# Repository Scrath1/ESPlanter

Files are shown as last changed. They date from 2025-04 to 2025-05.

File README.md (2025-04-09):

# ESPlanter - An ESP32-based smart planter system for use with Homeassistant



A smart planter based on an ESP32 which integrates to homeassistant using
the MQTT integration and by sending an auto-discovery message.

The planter itself does not decide on when water is needed. It only exposes its
sensors and a button (to trigger the pump) for the homeassistant server to control.

## Required Parts:
- 1x Seeed XIAO ESP32C3
  (If you want to use a different device, modify the platformio.ini file)
- 5V Mini 360 Self-priming water pump
- 1x NPN Transistor which can handle the pump current.
  I used a BC107A because I had a couple already.
- 1x BH1750 light sensor
- 1x Capacitive Soil moisture sensor
- 1x 220 Ohm resistor
- 1x Diode
- Connectors if you want to use them
- Flexible tube for the water pump. Mine has an inner diameter of 4mm but make sure
  to check your pump if you require a different diameter.

## Circuit diagram
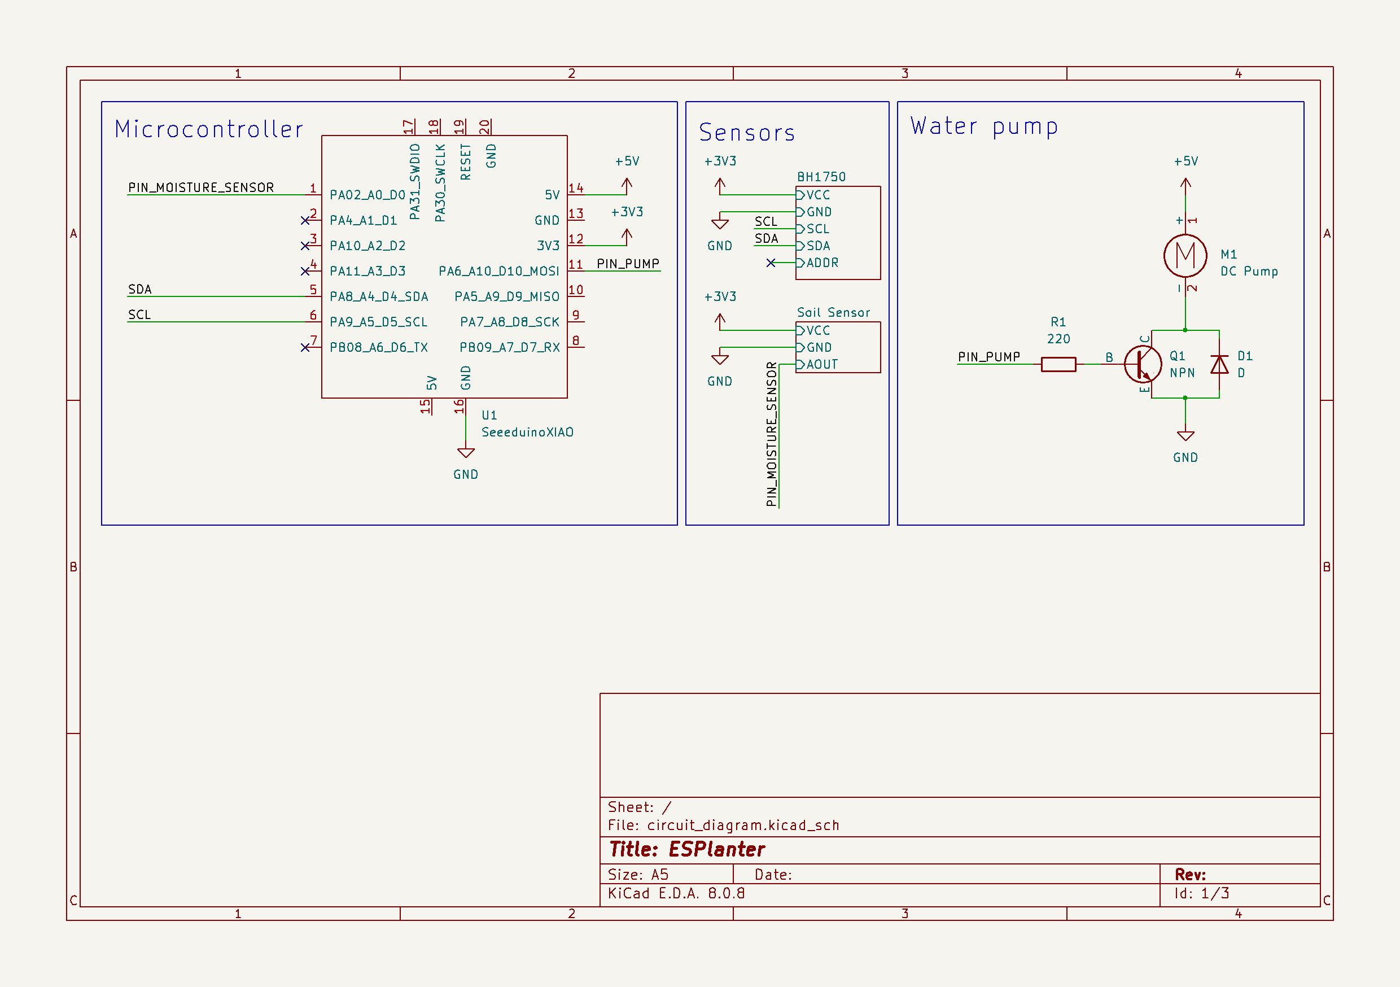
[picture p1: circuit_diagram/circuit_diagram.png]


## Setup
After flashing the device open the serial monitor to configure it.
Type `help` and confirm by pressing enter, to list all available commands.
Type `list` to print all currently supported configuration values and their current
values.

By typing `set <config value name>:<value>` you can change the value of these entries
for your particular setup. Important values to configure are the WiFi SSID and
password, the MQTT broker address as well as the username and password if your server
requires authentication.

## Calibrating the soil sensor
In order for the soil sensor to measure sensible values it needs to be calibrated.
To do this, use the serial interface and type the command `read_moisture_sensor`.
This will print the currently measured moisture as a percentage as well as the
raw value read by the ADC.

1. While the sensor is perfectly dry, obtain a raw sensor reading and set this
   as the upper limit (using the method described in [Setup](#setup)).
2. Take a cup of water and insert the sensor up to the printed line on the circuit
   board. Take another raw sensor reading and set this value as the lower limit.
3. Take a new sensor reading while the sensor is still in the water cup.
   The percentage should now show approximately 100% moisture.

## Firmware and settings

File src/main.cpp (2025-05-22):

#include <Arduino.h>
#include <LittleFS.h>

#include "drivers/light_sensor.h"
#include "drivers/pump.h"
#include "drivers/soil_sensor.h"
#include "global.h"
#include "mqtt_functions.h"
#include "serial_commands.h"
#include "static_config.h"
#include "wifi_functions.h"

#define FORMAT_LITTLEFS_IF_FAILED true

bool wifi_setup_success = false;

CfgRet_t config_littleFSSaveToFile(const ConfigTable_t* cfg, const char* filename) {
    if(cfg == NULL || filename == NULL) return CFG_RC_ERROR_NULLPTR;
    fs::File file = LittleFS.open(filename, FILE_WRITE);
    if(!file) return CFG_RC_ERROR;
    char line[FILE_MAX_LINE_LEN] = "";
    // iterate over all config entries
    bool line_length_error = false;
    bool encoding_error = false;
    for(uint32_t i = 0; i < cfg->count; i++) {
        const ConfigEntry_t e = cfg->entries[i];
        int32_t ret;
        switch(e.type) {
            default:
            case CONFIG_NONE:
                continue;
            case CONFIG_BOOL:
                ret = snprintf(line, sizeof(line), "%s: %u\n", e.key, *(bool*)e.value);
                break;
            case CONFIG_UINT32:
                ret = snprintf(line, sizeof(line), "%s: %lu\n", e.key, *(uint32_t*)e.value);
                break;
            case CONFIG_INT32:
                ret = snprintf(line, sizeof(line), "%s: %i\n", e.key, *(int32_t*)e.value);
                break;
            case CONFIG_FLOAT:
                ret = snprintf(line, sizeof(line), "%s: %f\n", e.key, *(float*)e.value);
                break;
            case CONFIG_STRING:
                ret = snprintf(line, sizeof(line), "%s: %s\n", e.key, e.value);
                break;
        }
        // Check if snprintf was successful
        if(ret > sizeof(line))
            line_length_error = true;
        else if(ret < 0)
            encoding_error = true;
        else {
            // write to file
            file.print(line);
        }
    }
    // close file
    file.close();

    if(encoding_error) return CFG_RC_ERROR_INVALID;
    if(line_length_error) return CFG_RC_ERROR_INCOMPLETE;
    return CFG_RC_SUCCESS;
}

CfgRet_t config_littleFSloadFromFile(ConfigTable_t* cfg, const char* filename) {
    if(cfg == NULL || filename == NULL) return CFG_RC_ERROR_NULLPTR;
    fs::File file = LittleFS.open(filename, FILE_READ);
    if(!file) return CFG_RC_ERROR;

    String lineStr = "";
    char line[FILE_MAX_LINE_LEN] = "";
    bool parsing_error_occurred = false;
    // Read each line
    while(file.available()) {
        lineStr = file.readStringUntil('\n');
        uint32_t line_len = lineStr.length();
        if(line_len == 0) continue;

        // copy into c string for compatibility with library functions
        strncpy(line, lineStr.c_str(), lineStr.length() + 1);
        if(CFG_RC_SUCCESS != config_parseKVStr(cfg, line, line_len + 1)) {
            // If any line could not be matched to a valid entry, set a flag
            parsing_error_occurred = true;
        }
        // reset line
        line[0] = '\0';
    }
    file.close();

    if(parsing_error_occurred) return CFG_RC_ERROR_INCOMPLETE;
    return CFG_RC_SUCCESS;
}

void setup() {
    Serial.begin(115200);
    Serial.println("ESPlanter");
    // put your setup code here, to run once:
    stint.setAutoBackspace(true);

    pump_init();
    init_light_sensor();

    if(!LittleFS.begin(FORMAT_LITTLEFS_IF_FAILED)) {
        Serial.println("Failed to initialize filesystem");
        while(1);
    }
    config_setSaveLoadFunctions(config_littleFSSaveToFile, config_littleFSloadFromFile);
    if(!LittleFS.exists(CONFIG_FILE_NAME)) {
        if(CFG_RC_SUCCESS != config_saveToFile(&config_table, CONFIG_FILE_NAME)) {
            Serial.println("Failed to create default config file");
            while(1);
        } else {
            Serial.println("Created default config file");
        }

    } else {
        CfgRet_t ret = config_loadFromFile(&config_table, CONFIG_FILE_NAME);
        switch(ret) {
            case CFG_RC_SUCCESS:
                Serial.println("Loaded config from file");
                break;
            case CFG_RC_ERROR_INCOMPLETE:
                Serial.println("Config contains unknown keys or a key-value pair could not be parsed");
                break;
            default:
                Serial.println("Failed to load config from file");
                while(1);
        }
    }
    // set default config values for config options which can not be
    // set at compile-time if no value was found in config file
    if(strlen(config.mqtt.client_id) == 0)
        snprintf(config.mqtt.client_id, sizeof(config.mqtt.client_id), "ESPlanter-%llX", ESP.getEfuseMac());
    if(strlen(config.mqtt.device_topic) == 0)
        snprintf(config.mqtt.device_topic, sizeof(config.mqtt.device_topic), "%llX", ESP.getEfuseMac());
    if(strlen(config.wifi.hostname) == 0)
        snprintf(config.wifi.hostname, sizeof(config.wifi.hostname), "ESPlanter-%llX", ESP.getEfuseMac());

    if(strlen(config.wifi.ssid) > 0) {
        Serial.println("Setting up WiFi");
        wifi_setup_success = wifi_setup();
    } else {
        Serial.println("No SSID configured. Skipping WiFi setup");
    }
    mqtt_setup();

    Serial.println("Setup complete.\n\nType 'help' for a list of possible commands.");
    Serial.println("Press enter to confirm a command");
}

void handle_serial_input() {
    bool skip_next_newline = false;
    while(Serial.available() > 0) {
        char c = Serial.read();
        // stupid handling of \r\n newlines
        // since some systems send just \r or just \n
        // for a newline and both individually trigger the command parser
        if(c == '\r') {
            Serial.println();
            skip_next_newline = true;
        } else if(c == '\n' && !skip_next_newline) {
            Serial.println();
        } else if(c == '\n' && skip_next_newline) {
            skip_next_newline = false;
        } else if(c == '\b') {
            // backspace implementation
            Serial.print("\b \b");  // erases last char from terminal
            // Erasing the last char from the stint buffer is handled automatically
            // by the ingest function
        } else
            Serial.print(c);

        Stint::ErrorCode ret = stint.ingest(c);
        switch(ret) {
            default:
                break;
            case Stint::BUFFER_FULL:
                Serial.println("Input buffer full without valid command. Clearing buffer!");
                stint.clearBuffer();
                break;
            case Stint::NO_MATCH:
                Serial.println("No matching command found");
                break;
        }
    }
}

void handle_mqtt() {
    static uint32_t next_sensor_poll_ticktime = 0;

    // check that WiFi is connected before trying MQTT stuff
    if(!WiFi.isConnected()) return;

    mqtt_maintain_connection();
    // same for the MQTT client
    if(!mqttClient.connected()) return;

    if(next_sensor_poll_ticktime <= xTaskGetTickCount()) {
        // set next time when the sensors should be polled again
        next_sensor_poll_ticktime = xTaskGetTickCount() + MQTT_DEFAULT_UPDATE_INTERVAL_MS;

        // Poll sensors and publish values
        char topic[MAX_TOPIC_STRING_SIZE] = "";
        char val_str[32] = "";
        // get light reading
        snprintf(topic, sizeof(topic), "%s/%s/lux", MQTT_BASE_TOPIC, config.mqtt.device_topic);
        snprintf(val_str, sizeof(val_str), "%i", get_lux_reading());
        mqttClient.publish(topic, val_str);

        // Get soil reading
        snprintf(topic, sizeof(topic), "%s/%s/moisture", MQTT_BASE_TOPIC, config.mqtt.device_topic);
        snprintf(val_str, sizeof(val_str), "%i", soil_sensor_get_moisture_percentage());
        mqttClient.publish(topic, val_str);

        // Also publish the currently configured pump run duration
        extern char pump_duration_topic[MAX_TOPIC_STRING_SIZE];
        snprintf(val_str, sizeof(val_str), "%lu", config.pump_duration_ms);
        mqttClient.publish(pump_duration_topic, val_str);
    }
    // ToDo: Apply filter to sensor readings

    // Work through accumalated mqtt library tasks
    if(!mqttClient.loop()) Serial.println("Error while running mqtt loop function");
}

void loop() {
    // put your main code here, to run repeatedly:
    handle_serial_input();

    if(wifi_setup_success){
        handle_mqtt();
    }
}

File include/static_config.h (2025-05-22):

#ifndef STATIC_CONFIG_H
#define STATIC_CONFIG_H

/**
 * The purpose of this file is to declare macros for compile-time configuration
 * which can not be changed at runtime, e.g. pinouts
 */

// Hardware configuration
// ============================================

// Pump pin
#define PIN_PUMP (D10)
// Default value for the pump duration. Can be overwritten at runtime
#define DEFAULT_PUMP_DURATION_MS (3000)
// Soil sensor pin
#define PIN_SOIL_SENSOR (A0)
// Calibration values for the raw adc values of the moisture sensor.
// You can preset these at compile time or overwrite them at runtime
#define MOISTURE_RAW_LOWER_LIMIT (0)
#define MOISTURE_RAW_UPPER_LIMIT (4095)
// Absolute maximum continuous runtime of the pump in milliseconds
#define MAX_PUMP_RUNTIME_MS (60000)

// String allocation limits
// ============================================

// Maximum length of the SSID string including null-terminator
#define MAX_WIFI_SSID_LEN (64)
// Maximum length of the password string including null-terminator
#define MAX_WIFI_PASSWORD_LEN (64)
// Maximum length of the wifi hostname string including null-terminator
#define MAX_WIFI_HOSTNAME_LEN (64)
// Maximum length of the mqtt broker address string including null-terminator
#define MAX_MQTT_BROKER_ADDRESS_LEN (64)
// Max string length for the MQTT Client ID
#define MAX_MQTT_CLIENT_ID_LEN (64)
// Max string length for the MQTT Username
#define MAX_MQTT_USERNAME_LEN (64)
// Max string length for the MQTT password
#define MAX_MQTT_PASSWORD_LEN (64)
// Max string length for the device topic config option
#define MAX_MQTT_DEVICE_TOPIC_LEN (64)
// Number of bytes that can fit into the serial command buffer
#define SERIAL_CMD_INPUT_BUFFER_SIZE (256)
// Maximum string length allocated for topic strings
#define MAX_TOPIC_STRING_SIZE (256)
// Maximum string length for the MQTT auto-discovery message for homeassistant
#define MAX_AUTO_DISCOVERY_MSG_LEN (2048)
// Maximum string length for the base topic of the homeassistant auto discovery
#define MAX_MQTT_DISCOVERY_TOPIC_LEN (64)

// MQTT configuration
// ============================================

// Defines in seconds how long to keep the mqtt connection open when
// no packages are being sent or received
#define MQTT_CONNECTION_KEEPALIVE_S 15
// Base topic for MQTT: <base topic>/<device name>/<interface>
#define MQTT_BASE_TOPIC "ESPlanter"
// Default interval for how often updated sensor readings are sent to the server
#define MQTT_DEFAULT_UPDATE_INTERVAL_MS (15000)
// Defines how many seconds after a failed connection attempt to the MQTT server
// the next attempt is made
#define MQTT_CONNECTION_RETRY_INTERVAL_S (60)

// Other
// ============================================

// Name of the general configuration file. Keep in mind that
// LittleFS requires absolute file paths.
#define CONFIG_FILE_NAME "/config.txt"

// Time in ms after which the ESP will give up trying to connect to an WiFi station
#define WIFI_CONNECTION_TIMEOUT_MS 5000

// Device information
// ============================================
#define MANUFACTURER "Scrath"
#define MODEL "ESPlanter"
#define SW_VERSION "1.0"
#define HW_VERSION "1.0"
#define SW_URL "https://github.com/Scrath1/ESPlanter"

#endif  // STATIC_CONFIG_H

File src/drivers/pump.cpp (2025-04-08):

#include "drivers/pump.h"

#include <Arduino.h>

#include "static_config.h"

#define PUMP_TIMER_NAME "Pump Cb Timer"
#define PUMP_ACTIVE_LEVEL 1
#define PUMP_INACTIVE_LEVEL 0

TimerHandle_t pump_callback_timer;
bool pump_running = false;

void pump_timer_callback_func(TimerHandle_t xtimer) {
    digitalWrite(PIN_PUMP, PUMP_INACTIVE_LEVEL);
    pump_running = false;
}

void pump_init() {
    pinMode(PIN_PUMP, OUTPUT);
    digitalWrite(PIN_PUMP, PUMP_INACTIVE_LEVEL);
    pump_running = false;
    pump_callback_timer = xTimerCreate(PUMP_TIMER_NAME, 1000, pdFALSE, 0, pump_timer_callback_func);
}

void pump_run(uint32_t duration_ms) {
    // Stop timer in case it was running and set new time until callback
    if(duration_ms == 0) {
        digitalWrite(PIN_PUMP, PUMP_INACTIVE_LEVEL);
        xTimerStop(pump_callback_timer, portMAX_DELAY);
        pump_running = false;
    } else {
        xTimerStop(pump_callback_timer, portMAX_DELAY);
        xTimerChangePeriod(pump_callback_timer, pdMS_TO_TICKS(duration_ms), portMAX_DELAY);
        xTimerStart(pump_callback_timer, portMAX_DELAY);

        digitalWrite(PIN_PUMP, PUMP_ACTIVE_LEVEL);
        pump_running = true;
    }
}

bool pump_is_running() { return pump_running; }

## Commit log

2025-04-02 pump working
2025-04-05 Added reset command and backspace functionality to terminal
    [main.cpp, serial_commands.cpp]
2025-04-05 Fixed configuration not being saved to filesystem
    [main.cpp, serial_commands.cpp]
2025-04-05 Added default values for hostname, clientID and device topic
2025-04-06 MQTT and sensor polling working
2025-04-06 Fixed bug with pump callback timer causing crash with duration=0
    [pump.cpp]
2025-04-06 Removed separate MQTT task to simplify program flow
2025-04-06 Switched to different mqtt library
2025-04-08 Minor refactoring to pump driver
2025-04-08 Changed pump MQTT interface
    Now using a duration topic and a separate trigger topic
2025-04-08 Fixed wrong config data type for pump duration
2025-04-08 Fixed bug causing pump duration to not be saved, updated libraries
    [mqtt_functions.cpp]
2025-04-09 Added runtime configurable moisture sensor calibration
2025-04-09 Added circuit diagram, filled out README and added a license
    [bh1750.kicad_sch, circuit_diagram.kicad_pcb, circuit_diagram.kicad_sch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]
2025-05-22 Fixed serial spam on unsuccesful wifi or mqtt connection
    [main.cpp, serial_commands.cpp, static_config.h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]
